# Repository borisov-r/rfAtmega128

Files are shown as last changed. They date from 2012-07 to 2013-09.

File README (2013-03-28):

Simple PCB with ATmega128RFa1 processor and usb. 
Main application of this board will be in our RepRap projects.

This work is licensed under the GNU GPL v3 or (at the user's discretion) any later version.
Software that will be used in this project is completely free and should be licensed under GPL v2 or later.

As a pins and code reference I'll use zigduino project:
http://www.logos-electro.com/zigduino/

============================================================================

Components:
1. ATmega128RFa1 -> 64 pins QFN @ 3.3 V
2. FT232RL       -> 28 pins     @ 3.3 V
3. BA033         -> 5 pins      @ -0.3 - 35 V
4. 2450FB15L0001 -> 6 pins      - RF balun
5. MCP809T-270I/TT -> added to RESET pin for programming
6. tunning capacitors -> 22 pF, 0.5 - 1.5 pF, 0603
7. RPSMA connector or PCB antenna
8. ICSP connector

============================================================================

Basic processes of the foundries should be examined and compared, so a simplified
trasistor model could be generated for more universal design.

Other option is a model to be generated according the needs and after that the most
suitable foundry should be chosen.

============================================================================

Schematic and layout design will be done using KiCAD.
Eventually a 3D models of the components will be added to the PCB.

============================================================================

Additional software for testing should be implemented.

Main RF libraries:
http://www.nongnu.org/uracoli/
http://freaklabs.org/index.php/chibiArduino.html
http://www.contiki-os.org
https://github.com/erictj/uracoli/tree/master/wibo
https://github.com/maniacbug/contiki-avr-zigduino
http://code.google.com/p/looci/wiki/GettingStartedContikiAVRRaven

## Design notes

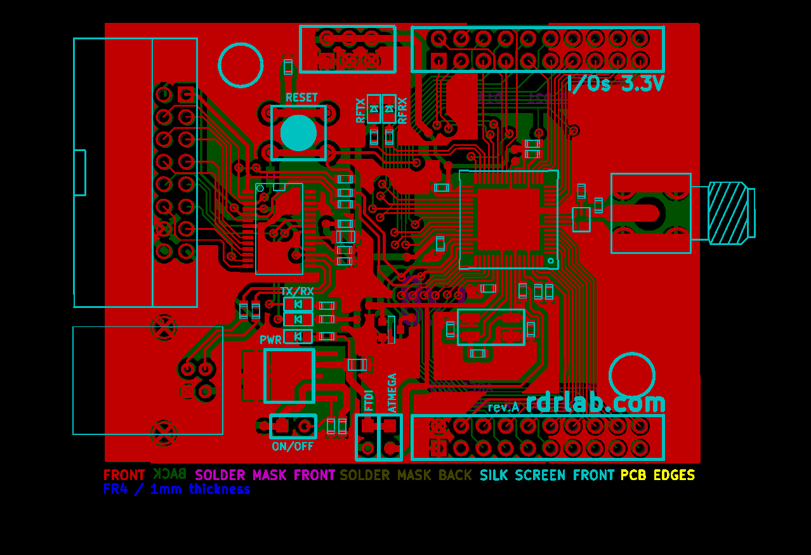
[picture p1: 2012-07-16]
hardware/rev.A/images/rfAtmega128-front.png

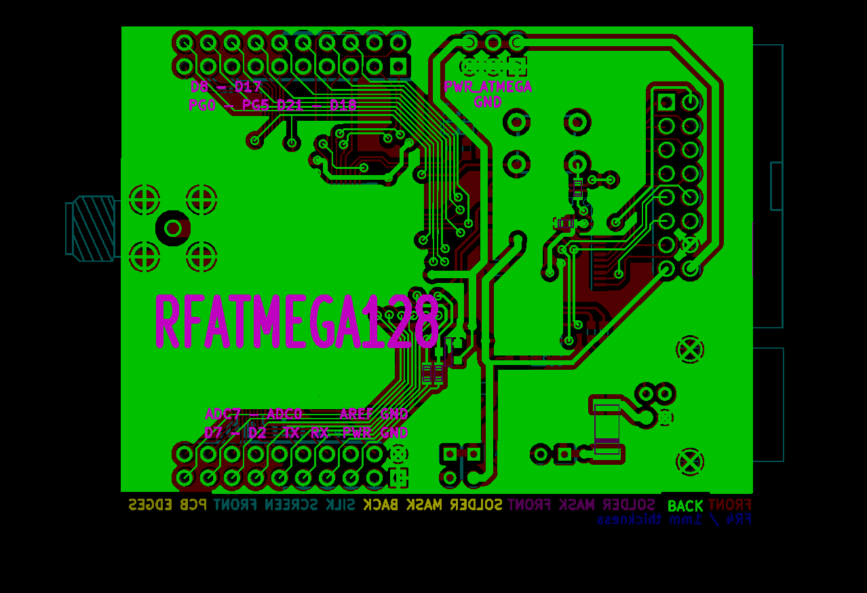
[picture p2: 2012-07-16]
hardware/rev.A/images/rfAtmega128-back.png

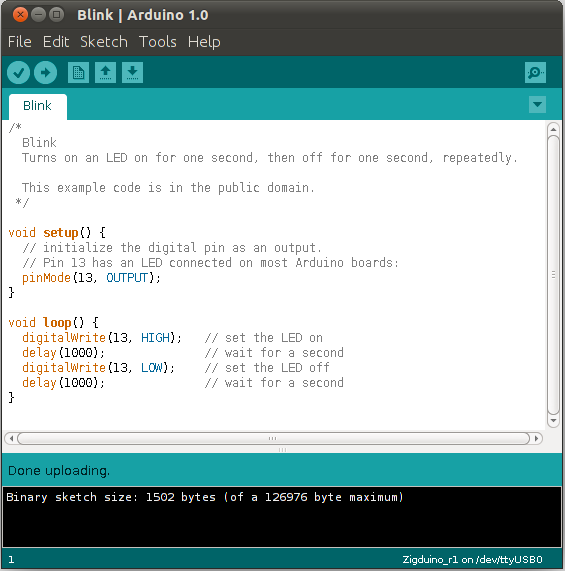
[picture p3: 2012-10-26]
hardware/rev.A/images/arduinoScreenshot.png

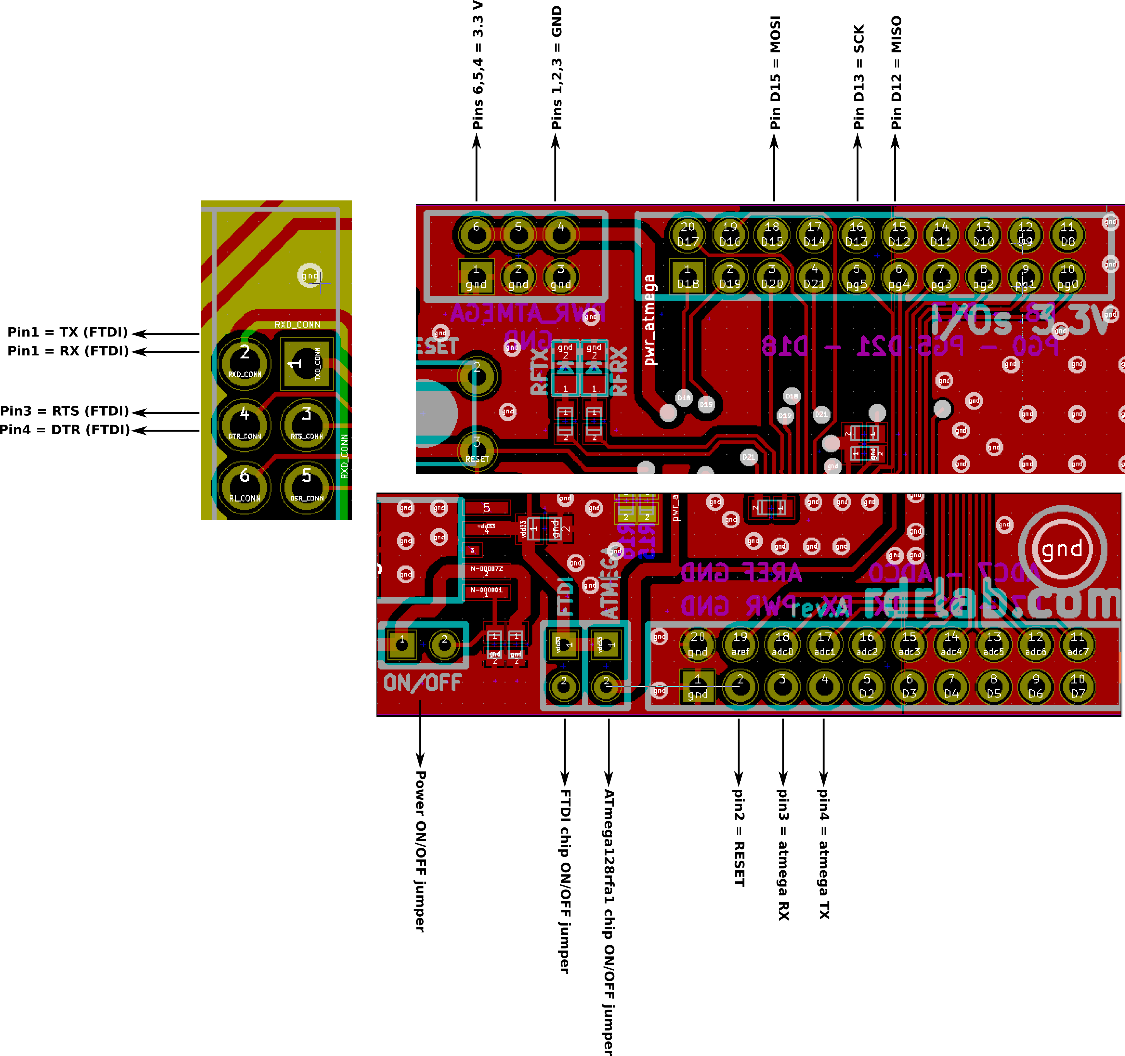
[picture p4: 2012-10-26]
hardware/rev.A/images/layoutPins.png

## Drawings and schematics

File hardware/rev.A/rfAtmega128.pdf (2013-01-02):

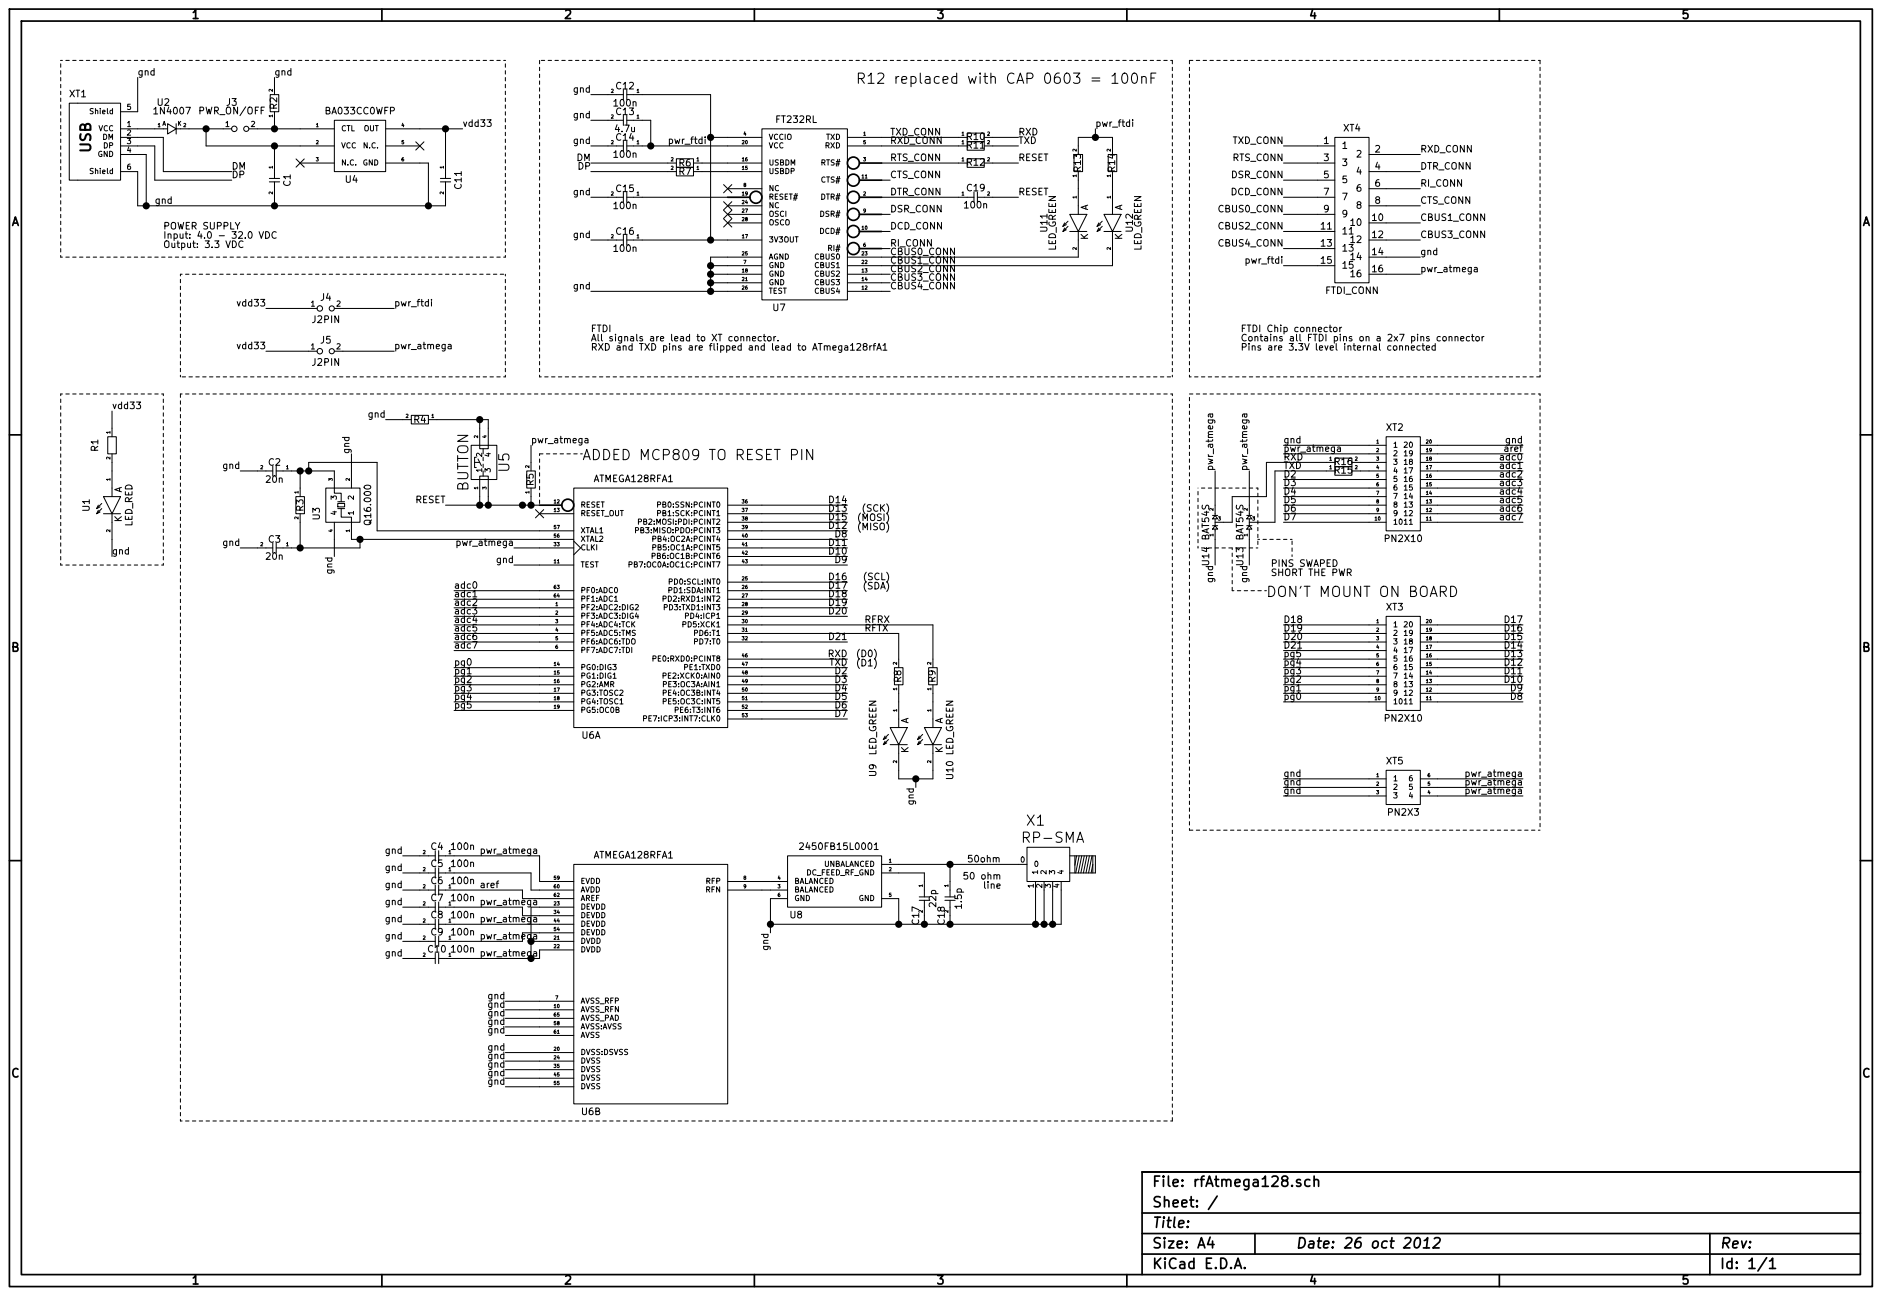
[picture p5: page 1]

POWER SUPPLY
Input: 4.0 - 32.0 VDC Output: 3.3 VDC

FTDI All signals are lead to XT connector. RXD and TXD pins are flipped and lead to ATmega128rfA1

FTDI Chip connector Contains all FTDI pins on a 2x7 pins connector Pins are 3.3V level internal connected

ADDED MCP809 TO RESET PIN

PINS SWAPED
DON'T MOUNT ON BOARD

1 2 C1722p gnd UNBALANCED 1 DC_FEED_RF_GND 2 BALANCED 3 BALANCED 4 GND 5 GND 6 U8

Id: 1/1 Title: File: rfAtmega128.sch
Sheet: /

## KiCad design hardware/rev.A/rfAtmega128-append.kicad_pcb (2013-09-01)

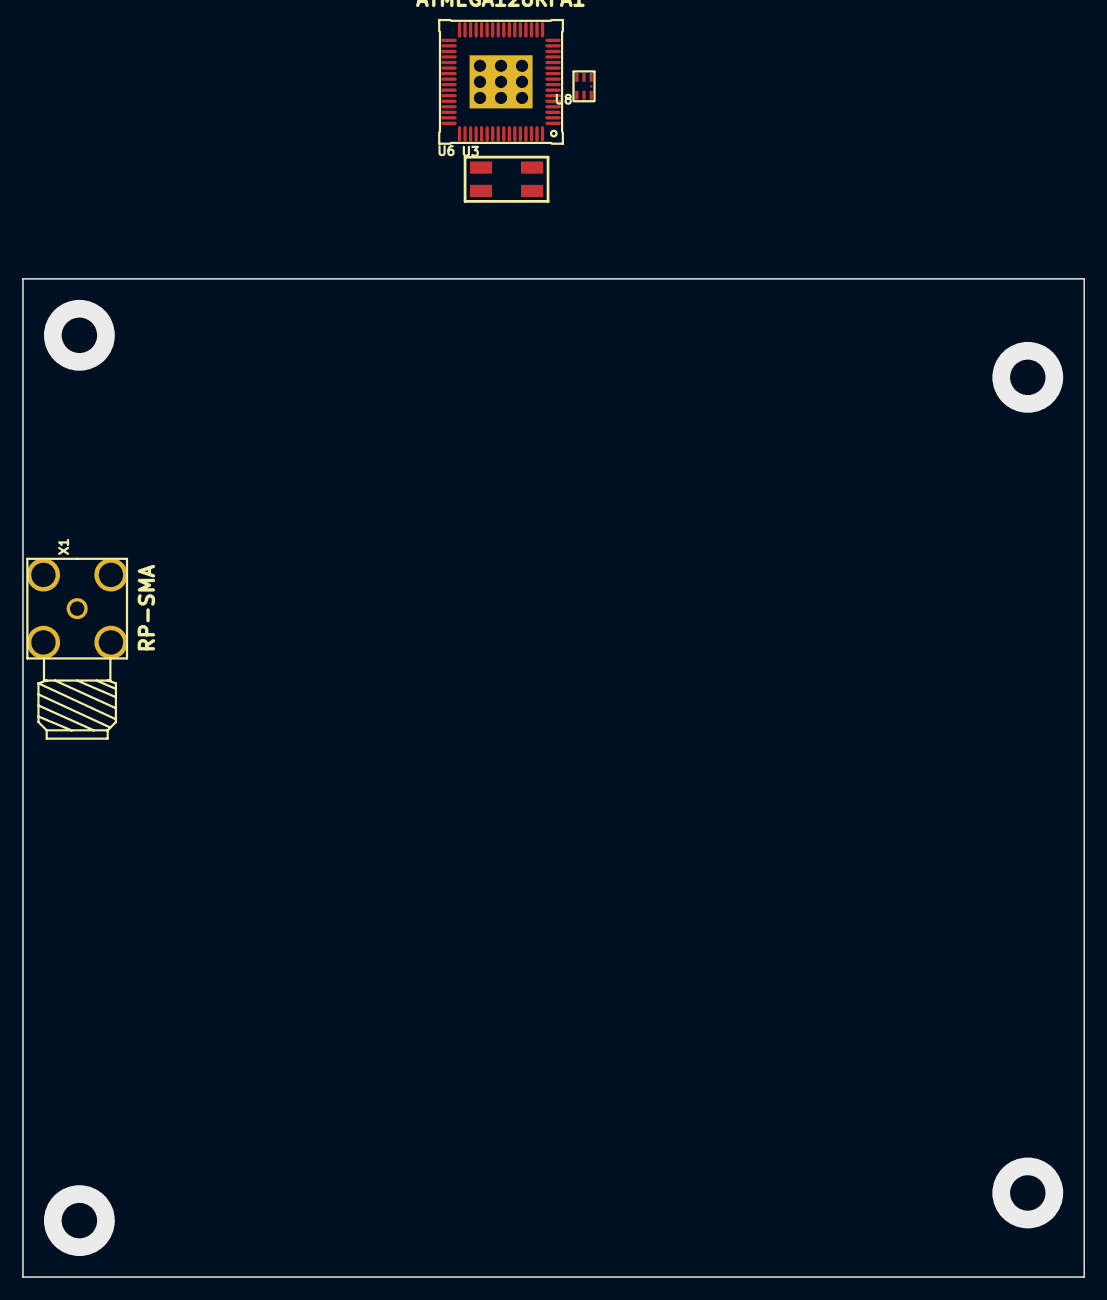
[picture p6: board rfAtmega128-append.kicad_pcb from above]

Board: 2 copper layers, 95.9 x 90.2 mm, 4 parts (0 on the bottom side), 6 nets, no tracks yet.

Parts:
U3: Q16.000; crystal_xg6x3p5
U6: ATMEGA128RFA1; atmega128rfa1
U8: 2450FB15L0001
X1: RP-SMA; rp-sma

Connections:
/gnd: U3.2, U3.4, U6.7, U6.10, U6.11, U6.20, U6.24, U6.35, U6.45, U6.55, U6.58, U6.61, U6.65, U8.5, U8.6
/pwr_atmega: U6.21, U6.22, U6.23, U6.33, U6.34, U6.44, U6.54, U6.59
unnamed: U3.1, U6.56
unnamed: U6.8, U8.4
unnamed: U6.9, U8.3
unnamed: U3.3, U6.57

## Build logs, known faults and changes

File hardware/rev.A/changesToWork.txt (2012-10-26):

R12 -> replaced with cap 100 nF
R5 = 30 kOhms instead of 100 kOhms
MCP809 on reset circuit.

0. Download Zigduino from: 

1. get fuses from boards Zigduino -> ~/git/Zigduino/arduino/cat boards.txt

-U lfuse:w:0xFF:m -U hfuse:w:0x9A:m -U efuse:w:0xF5:m -U lock:w:0x0F:m

##############################################################

zigduino.name=Zigduino

zigduino.upload.protocol=arduino
zigduino.upload.maximum_size=126976
zigduino.upload.speed=57600

zigduino.bootloader.low_fuses=0xFF
zigduino.bootloader.high_fuses=0xDA
zigduino.bootloader.extended_fuses=0xF5
zigduino.bootloader.path=atmega
zigduino.bootloader.file=ATmegaBOOT_168_atmega128rfa1.hex
zigduino.bootloader.unlock_bits=0x3F
zigduino.bootloader.lock_bits=0x0F

zigduino.build.mcu=atmega128rfa1
zigduino.build.f_cpu=16000000L
zigduino.build.core=zigduino

##############################################################

2. set fuses
sudo avrdude -c usbasp -p ATMEGA128RFA1 -U lfuse:w:0xFF:m -U hfuse:w:0x9A:m -U efuse:w:0xF5:m -U lock:w:0x0F:m

avrdude: warning: cannot set sck period. please check for usbasp firmware update.
avrdude: AVR device initialized and ready to accept instructions

Reading | ################################################## | 100% 0.01s

avrdude: Device signature = 0x1ea701
avrdude: reading input file "0xFF"
avrdude: writing lfuse (1 bytes):

Writing | ################################################## | 100% 0.01s

avrdude: 1 bytes of lfuse written
avrdude: verifying lfuse memory against 0xFF:
avrdude: load data lfuse data from input file 0xFF:
avrdude: input file 0xFF contains 1 bytes
avrdude: reading on-chip lfuse data:

Reading | ################################################## | 100% 0.00s

avrdude: verifying ...
avrdude: 1 bytes of lfuse verified
avrdude: reading input file "0x9A"
avrdude: writing hfuse (1 bytes):

Writing | ################################################## | 100% 0.02s

avrdude: 1 bytes of hfuse written
avrdude: verifying hfuse memory against 0x9A:
avrdude: load data hfuse data from input file 0x9A:
avrdude: input file 0x9A contains 1 bytes
avrdude: reading on-chip hfuse data:

Reading | ################################################## | 100% 0.00s

avrdude: verifying ...
avrdude: 1 bytes of hfuse verified
avrdude: reading input file "0xF5"
avrdude: writing efuse (1 bytes):

Writing | ################################################## | 100% 0.02s

avrdude: 1 bytes of efuse written
avrdude: verifying efuse memory against 0xF5:
avrdude: load data efuse data from input file 0xF5:
avrdude: input file 0xF5 contains 1 bytes
avrdude: reading on-chip efuse data:

Reading | ################################################## | 100% 0.00s

avrdude: verifying ...
avrdude: 1 bytes of efuse verified
avrdude: reading input file "0x0F"
avrdude: writing lock (1 bytes):

Writing | ################################################## | 100% 0.02s

avrdude: 1 bytes of lock written
avrdude: verifying lock memory against 0x0F:
avrdude: load data lock data from input file 0x0F:
avrdude: input file 0x0F contains 1 bytes
avrdude: reading on-chip lock data:

Reading | ################################################## | 100% 0.00s

avrdude: verifying ...
avrdude: 1 bytes of lock verified

avrdude: safemode: Fuses OK

avrdude done.  Thank you.

3. upload the bootloader
~/git/Zigduino/arduino/bootloaders/atmega$ sudo avrdude -c usbasp -p ATMEGA128RFA1 -U flash:w:ATmegaBOOT_168_atmega128rfa1.hex

avrdude: warning: cannot set sck period. please check for usbasp firmware update.
avrdude: AVR device initialized and ready to accept instructions

Reading | ################################################## | 100% 0.01s

avrdude: Device signature = 0x1ea701
avrdude: NOTE: FLASH memory has been specified, an erase cycle will be performed
         To disable this feature, specify the -D option.
avrdude: erasing chip
avrdude: warning: cannot set sck period. please check for usbasp firmware update.
avrdude: reading input file "ATmegaBOOT_168_atmega128rfa1.hex"
avrdude: input file ATmegaBOOT_168_atmega128rfa1.hex auto detected as Intel Hex
avrdude: writing flash (129132 bytes):

Writing | ################################################## | 100% 23.79s

avrdude: 129132 bytes of flash written
avrdude: verifying flash memory against ATmegaBOOT_168_atmega128rfa1.hex:
avrdude: load data flash data from input file ATmegaBOOT_168_atmega128rfa1.hex:
avrdude: input file ATmegaBOOT_168_atmega128rfa1.hex auto detected as Intel Hex
avrdude: input file ATmegaBOOT_168_atmega128rfa1.hex contains 129132 bytes
avrdude: reading on-chip flash data:

Reading | ################################################## | 100% 36.80s

avrdude: verifying ...
avrdude: 129132 bytes of flash verified

avrdude: safemode: Fuses OK

avrdude done.  Thank you.

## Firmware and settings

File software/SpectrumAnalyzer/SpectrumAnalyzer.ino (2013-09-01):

/*

Run this sketch using a Zigduino and monitor the serial output
it will output comma separated data values when
you trigger it by sending something to the serial port

The comma separated format looks like
channel #, frequency, ED Level, RSSI

dump the data into a spreadsheet program and plot it out

try turning on other 2.4 GHz devices and see if the data changes

note that the valid channels for the PLL are from 11 to 26

*/

#include <ZigduinoRadio.h>

void setup()
{
  ZigduinoRadio.begin(11);
  Serial.begin(9600);
  
  ZigduinoRadio.attachError(errHandle);
  
  Serial.println(); // signal the start with a new line
}

void loop()
{
  //if (Serial.available()) {
  //  Serial.flush();
    
    char i;
    //for (i = 11; i <= 26; i++) {
    i = 11;
    ZigduinoRadio.setChannel(i);
    //  Serial.print(i, 10);
    //  Serial.print(",");
    //  Serial.print(((int16_t)(i*5))+2350, 10);
    //  Serial.print(",");
      Serial.print(ZigduinoRadio.getEdNow(), 10);
      Serial.println(",");
      delay(100);
    //  Serial.print(ZigduinoRadio.getRssiNow(), 10);
    //  Serial.println(",");
    //}
  //}
}

void errHandle(radio_error_t err)
{
  Serial.println();
  Serial.print("Error: ");
  Serial.print((uint8_t)err, 10);
  Serial.println();
}

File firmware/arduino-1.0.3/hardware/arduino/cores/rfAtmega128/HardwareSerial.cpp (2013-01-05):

/*
  HardwareSerial.cpp - Hardware serial library for Wiring
  Copyright (c) 2006 Nicholas Zambetti.  All right reserved.

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
  Modified 23 November 2006 by David A. Mellis
  Modified 28 September 2010 by Mark Sproul
*/

#include <stdlib.h>
#include <stdio.h>
#include <string.h>
#include <inttypes.h>
#include "Arduino.h"
#include "wiring_private.h"

// this next line disables the entire HardwareSerial.cpp, 
// this is so I can support Attiny series and any other chip without a uart
#if defined(UBRRH) || defined(UBRR0H) || defined(UBRR1H) || defined(UBRR2H) || defined(UBRR3H)

#include "HardwareSerial.h"

// Define constants and variables for buffering incoming serial data.  We're
// using a ring buffer (I think), in which head is the index of the location
// to which to write the next incoming character and tail is the index of the
// location from which to read.
#if (RAMEND < 1000)
  #define SERIAL_BUFFER_SIZE 16
#else
  #define SERIAL_BUFFER_SIZE 64
#endif

struct ring_buffer
{
  unsigned char buffer[SERIAL_BUFFER_SIZE];
  volatile int head;
  volatile int tail;
};

#if defined(USBCON)
  ring_buffer rx_buffer = { { 0 }, 0, 0};
  ring_buffer tx_buffer = { { 0 }, 0, 0};
#endif
#if defined(UBRRH) || defined(UBRR0H)
  ring_buffer rx_buffer  =  { { 0 }, 0, 0 };
  ring_buffer tx_buffer  =  { { 0 }, 0, 0 };
#endif
#if defined(UBRR1H)
  ring_buffer rx_buffer1  =  { { 0 }, 0, 0 };
  ring_buffer tx_buffer1  =  { { 0 }, 0, 0 };
#endif
#if defined(UBRR2H)
  ring_buffer rx_buffer2  =  { { 0 }, 0, 0 };
  ring_buffer tx_buffer2  =  { { 0 }, 0, 0 };
#endif
#if defined(UBRR3H)
  ring_buffer rx_buffer3  =  { { 0 }, 0, 0 };
  ring_buffer tx_buffer3  =  { { 0 }, 0, 0 };
#endif

inline void store_char(unsigned char c, ring_buffer *buffer)
{
  int i = (unsigned int)(buffer->head + 1) % SERIAL_BUFFER_SIZE;

  // if we should be storing the received character into the location
  // just before the tail (meaning that the head would advance to the
  // current location of the tail), we're about to overflow the buffer
  // and so we don't write the character or advance the head.
  if (i != buffer->tail) {
    buffer->buffer[buffer->head] = c;
    buffer->head = i;
  }
}

#if !defined(USART0_RX_vect) && defined(USART1_RX_vect)
// do nothing - on the 32u4 the first USART is USART1
#else
#if !defined(USART_RX_vect) && !defined(SIG_USART0_RECV) && \
    !defined(SIG_UART0_RECV) && !defined(USART0_RX_vect) && \
	!defined(SIG_UART_RECV)
  #error "Don't know what the Data Received vector is called for the first UART"
#else
  void serialEvent() __attribute__((weak));
  void serialEvent() {}
  #define serialEvent_implemented
#if defined(USART_RX_vect)
  SIGNAL(USART_RX_vect)
#elif defined(SIG_USART0_RECV)
  SIGNAL(SIG_USART0_RECV)
#elif defined(SIG_UART0_RECV)
  SIGNAL(SIG_UART0_RECV)
#elif defined(USART0_RX_vect)
  SIGNAL(USART0_RX_vect)
#elif defined(SIG_UART_RECV)
  SIGNAL(SIG_UART_RECV)
#endif
  {
  #if defined(UDR0)
    unsigned char c  =  UDR0;
  #elif defined(UDR)
    unsigned char c  =  UDR;
  #else
    #error UDR not defined
  #endif
    store_char(c, &rx_buffer);
  }
#endif
#endif

#if defined(USART1_RX_vect)
  void serialEvent1() __attribute__((weak));
  void serialEvent1() {}
  #define serialEvent1_implemented
  SIGNAL(USART1_RX_vect)
  {
    unsigned char c = UDR1;
    store_char(c, &rx_buffer1);
  }
#elif defined(SIG_USART1_RECV)
  #error SIG_USART1_RECV
#endif

#if defined(USART2_RX_vect) && defined(UDR2)
  void serialEvent2() __attribute__((weak));
  void serialEvent2() {}
  #define serialEvent2_implemented
  SIGNAL(USART2_RX_vect)
  {
    unsigned char c = UDR2;
    store_char(c, &rx_buffer2);
  }
#elif defined(SIG_USART2_RECV)
  #error SIG_USART2_RECV
#endif

#if defined(USART3_RX_vect) && defined(UDR3)
  void serialEvent3() __attribute__((weak));
  void serialEvent3() {}
  #define serialEvent3_implemented
  SIGNAL(USART3_RX_vect)
  {
    unsigned char c = UDR3;
    store_char(c, &rx_buffer3);
  }
#elif defined(SIG_USART3_RECV)
  #error SIG_USART3_RECV
#endif

void serialEventRun(void)
{
#ifdef serialEvent_implemented
  if (Serial.available()) serialEvent();
#endif
#ifdef serialEvent1_implemented
  if (Serial1.available()) serialEvent1();
#endif
#ifdef serialEvent2_implemented
  if (Serial2.available()) serialEvent2();
#endif
#ifdef serialEvent3_implemented
  if (Serial3.available()) serialEvent3();
#endif
}


#if !defined(USART0_UDRE_vect) && defined(USART1_UDRE_vect)
// do nothing - on the 32u4 the first USART is USART1
#else
#if !defined(UART0_UDRE_vect) && !defined(UART_UDRE_vect) && !defined(USART0_UDRE_vect) && !defined(USART_UDRE_vect)
  #error "Don't know what the Data Register Empty vector is called for the first UART"
#else
#if defined(UART0_UDRE_vect)
ISR(UART0_UDRE_vect)
#elif defined(UART_UDRE_vect)
ISR(UART_UDRE_vect)
#elif defined(USART0_UDRE_vect)
ISR(USART0_UDRE_vect)
#elif defined(USART_UDRE_vect)
ISR(USART_UDRE_vect)
#endif
{
  if (tx_buffer.head == tx_buffer.tail) {
	// Buffer empty, so disable interrupts
#if defined(UCSR0B)
    cbi(UCSR0B, UDRIE0);
#else
    cbi(UCSRB, UDRIE);
#endif
  }
  else {
    // There is more data in the output buffer. Send the next byte
    unsigned char c = tx_buffer.buffer[tx_buffer.tail];
    tx_buffer.tail = (tx_buffer.tail + 1) % SERIAL_BUFFER_SIZE;
	
  #if defined(UDR0)
    UDR0 = c;
  #elif defined(UDR)
    UDR = c;
  #else
    #error UDR not defined
  #endif
  }
}
#endif
#endif

#ifdef USART1_UDRE_vect
ISR(USART1_UDRE_vect)
{
  if (tx_buffer1.head == tx_buffer1.tail) {
	// Buffer empty, so disable interrupts
    cbi(UCSR1B, UDRIE1);
  }
  else {
    // There is more data in the output buffer. Send the next byte
    unsigned char c = tx_buffer1.buffer[tx_buffer1.tail];
    tx_buffer1.tail = (tx_buffer1.tail + 1) % SERIAL_BUFFER_SIZE;
	
    UDR1 = c;
  }
}
#endif

#if defined(USART2_UDRE_vect) && defined(UBRR2H)
ISR(USART2_UDRE_vect)
{
  if (tx_buffer2.head == tx_buffer2.tail) {
	// Buffer empty, so disable interrupts
    cbi(UCSR2B, UDRIE2);
  }
  else {
    // There is more data in the output buffer. Send the next byte
    unsigned char c = tx_buffer2.buffer[tx_buffer2.tail];
    tx_buffer2.tail = (tx_buffer2.tail + 1) % SERIAL_BUFFER_SIZE;
	
    UDR2 = c;
  }
}
#endif

#if defined(USART3_UDRE_vect) && defined(UBRR3H)
ISR(USART3_UDRE_vect)
{
  if (tx_buffer3.head == tx_buffer3.tail) {
	// Buffer empty, so disable interrupts
    cbi(UCSR3B, UDRIE3);
  }
  else {
    // There is more data in the output buffer. Send the next byte
    unsigned char c = tx_buffer3.buffer[tx_buffer3.tail];
    tx_buffer3.tail = (tx_buffer3.tail + 1) % SERIAL_BUFFER_SIZE;
	
    UDR3 = c;
  }
}
#endif


// Constructors ////////////////////////////////////////////////////////////////
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

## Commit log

2012-04-03 added initial library with atmega128rfa1, r, l, c - 0603
    [arduinoRF.sch]
2012-04-03 added TANT_CAP_0603 to library
    [arduinoRF.sch]
2012-04-10 Added many components to schematic library and schematic changed.
    [arduinoRF.sch]
2012-04-17 modified components from schematic library and schematic optimized.
    [arduinoRF.sch]
2012-04-18 Added arduino kicad reference project, schematic almost finished, board layout.
    [$savepcb.brd, arduinoRF.brd, arduinoRF.sch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]
2012-04-19 Added pcb libraries and 3d models for the PCB. Added to some components in schematic datasheets and footprints.
    [$savepcb.brd, arduinoRF.sch, arduino_uno_r3_compatible.brd]
2012-04-20 Schmatics is more readable now and added most of the modules to the components with references.
    [$savepcb.brd, arduinoRF.sch, arduino_uno_r3_compatible.brd]
2012-04-23 Changes in schematic, board is modified and some lib files updated.
    [$savepcb.brd, arduinoRF.brd, arduinoRF.sch]
2012-04-26 Netlist and components list generated.
    [arduinoRF.sch]
2012-05-17 Added test board to the project and the initial netlist.
    [arduinoRF.brd, arduinoRF.sch, boardTests.brd]
2012-05-18 Old hardware design is now moved to folder v001 and new design is started in dev folder
    [$savepcb.brd, arduinoRF.brd, arduinoRF.sch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]
2012-05-21 New schematic to finish at home.
    [rfAtmega128.sch]
2012-05-22 dev board schematic is finished now. Need to add modules of few resistors and condensators.
    [boardTests.brd, rfAtmega128.sch]
2012-05-23 Initial pcb board layout started.
    [rfAtmega128.brd, rfAtmega128.sch]
2012-05-28 Board routing started and rf part done.
    [rfAtmega128.brd, rfAtmega128.sch]
2012-05-31 Most of ATmega128rfA1 pins are connected now. Additional power connector should be added with 2.54 mm stepping near to digital pins.
    [rfAtmega128.brd, rfAtmega128.sch]
2012-06-04 Removed test pads, atmega connectors are routed. FTDI connector needs routing.
    [rfAtmega128.brd, rfAtmega128.sch]
2012-06-05 board routed. size needs more precission and zone (copper pour) needs review.
    [rfAtmega128.brd, rfAtmega128.sch]
2012-06-06 Layout ready, needs 2 drills for mounting and copper pour (zones in kicad).
    [rfAtmega128.brd]
2012-06-06 Board is finished. Need to add grounding viases in RF part and some texts.
    [rfAtmega128.brd]
2012-06-07 Added RF viases, all viases are now 7 types. Generated gerber files and drills in production directory. All need review before sending for production.
    [rfAtmega128.brd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]
2012-06-08 Viases circles from comments layer moved to silkscreen layer. Drills exported in .drl file.
    [rfAtmega128.brd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]
2012-06-11 Board changed to be manufactured at iteadstudio.com. Added bottom SilkScreen and rfAtmega128china.brd.
    [$rfAtmega128.brd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]
2012-06-12 Directory structure changed in hardware. Board is now called rfAtmega128 rev.A and is send for manufacturing.
    [$rfAtmega128.brd, $savepcb.brd, arduinoRF.brd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]
2012-07-16 Added BOM of the board and fixed some resistor values in the schematic.
    [rfAtmega128.sch]
2012-07-18 Changed D1 to 1N4007 in the schematic.
    [rfAtmega128.sch]
2012-07-18 Modified BOM to use 1N4007 as a diode.
2012-07-20 Pins swapped of the RX and TX protective diodes marked on schematic. Resistor values of R6 and R7 changed to 0 in BOM and netlist.
    [rfAtmega128.sch]
2012-09-24 Added schematic in pdf format and pins explained on layout.
2012-10-26 Added some documentation files and updated schematic.
    [rfAtmega128.sch]
2013-01-05 Arduino IDE working and all DIO verified.
2013-01-05 All PWM working. ADC doesn't work yet.
2013-01-06 remove deprecated typedef avr-libc v1.8.0 more info in issue: https://github.com/arduino/Arduino/issues/795
2013-01-06 patch analogRead in wiring_analog.c and now all analog pins works fine
2013-01-07 Updated productionFiles for easier mounting of the components.
2013-09-01 Added Zigduino Radio Examples, CW and Spectrum analyzer
    [rfAtmega128-append.kicad_pcb, rfAtmega128.sch]
